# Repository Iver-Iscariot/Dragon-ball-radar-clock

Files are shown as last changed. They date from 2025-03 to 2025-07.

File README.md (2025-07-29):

# Dragon ball radar watch
A clock based on the dragon-radar from Dragon Ball.<br>
Very basic, pocket watch-style clock, with two rings of 12 LED's (hour/minute).<br>
At the press of the top button, the hour and minute (rounded to closest five) will pulse a couple of times, like in the anime.
&nbsp;

As this will be a novelty item that I only use once in a while, I will forgo a proper RTC, and just rely on the MCU itself for timekeeping. 
To work with the one-button interface of the original, I will set it such that a long-press will set the time to 12 o'clock, so you can simply set it when the actual time is 12 am or pm.<br>

&nbsp;



Progress so far. I need to turn a housing on the lathe

## VERY organized scematic:



## TODO for next PCB itteration:
 - Mosfet poweroff for 4052 multiplexer (power-saving)
 - Perhaps figure out more efficient way of driving the matrix than 4052 (IS31FL3746A LED driver ?)
 - Consider using dedicated RTC, to allow MCU sleep (power saving)
 - Attempt to move LED rings closer to center and make it smaller (LED driver chip would reduce total component footprint)
 - Try out a different LIPO charging circuit (there HAS to be a better way)

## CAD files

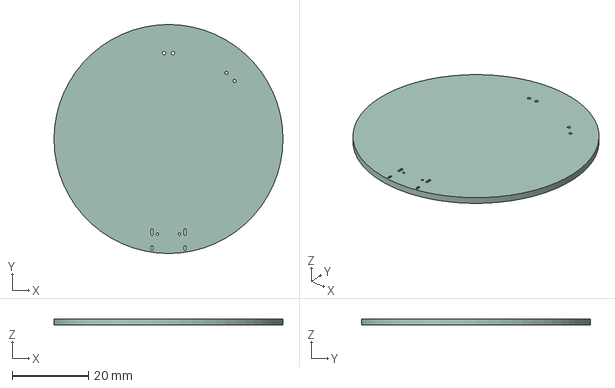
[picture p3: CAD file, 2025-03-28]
DB-radar/DB-radar.step
60.0 x 60.0 x 1.60 mm

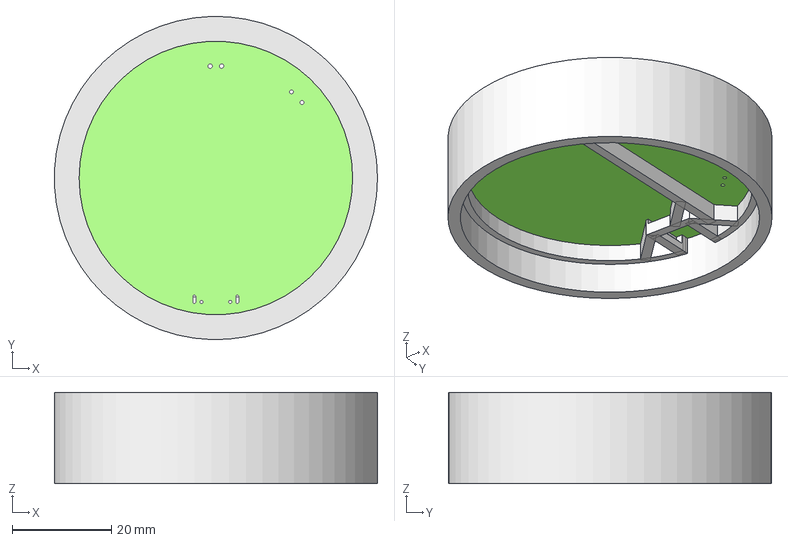
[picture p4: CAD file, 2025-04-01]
supportframes.FCStd
65.0 x 65.0 x 18.3 mm
DB-radar PCB
Front Spacer
Back support
Plexiglass

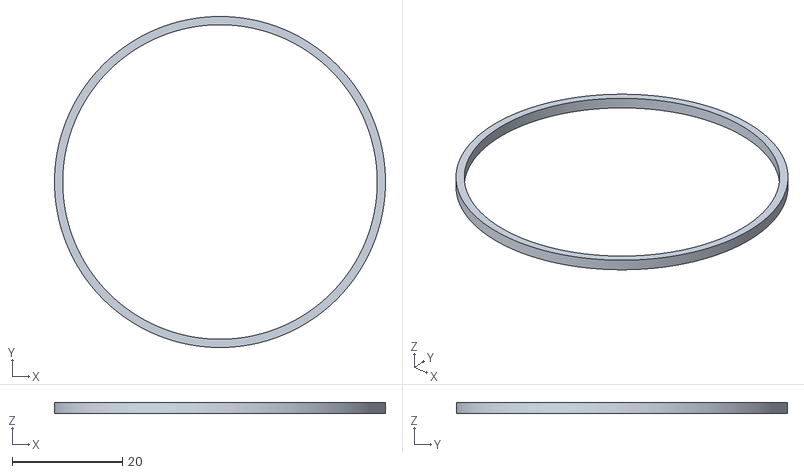
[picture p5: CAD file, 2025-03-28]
front spacer.stl
60.0 x 60.0 x 2.00

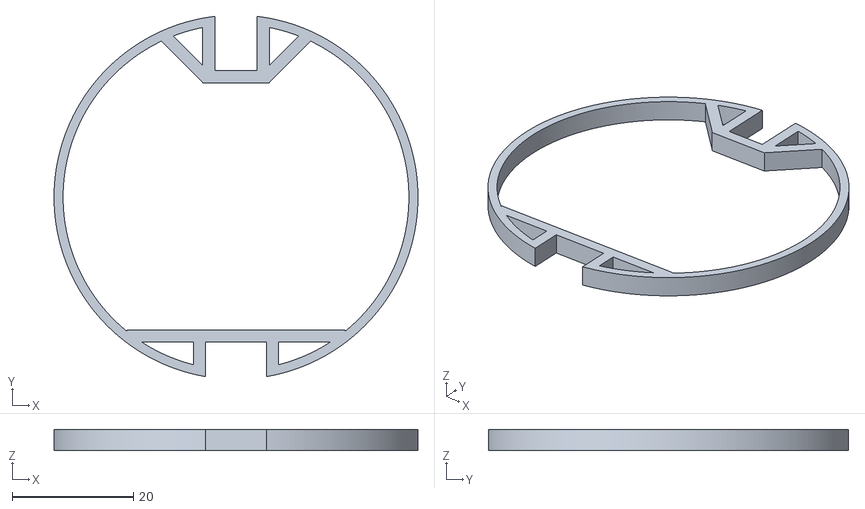
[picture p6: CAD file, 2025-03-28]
usb side.stl
60.0 x 59.4 x 3.50

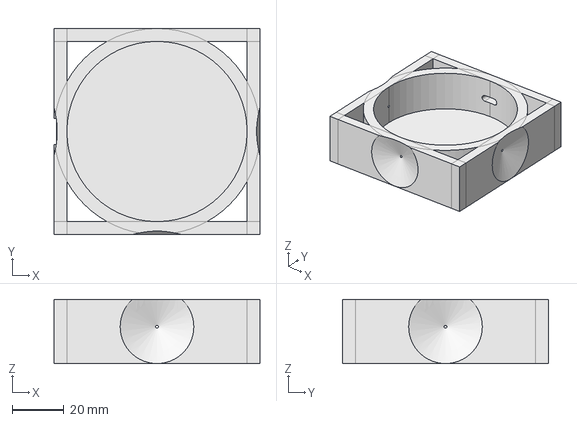
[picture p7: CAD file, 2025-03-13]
Drill guide 3D print.FCStd
80.0 x 80.0 x 25.0 mm

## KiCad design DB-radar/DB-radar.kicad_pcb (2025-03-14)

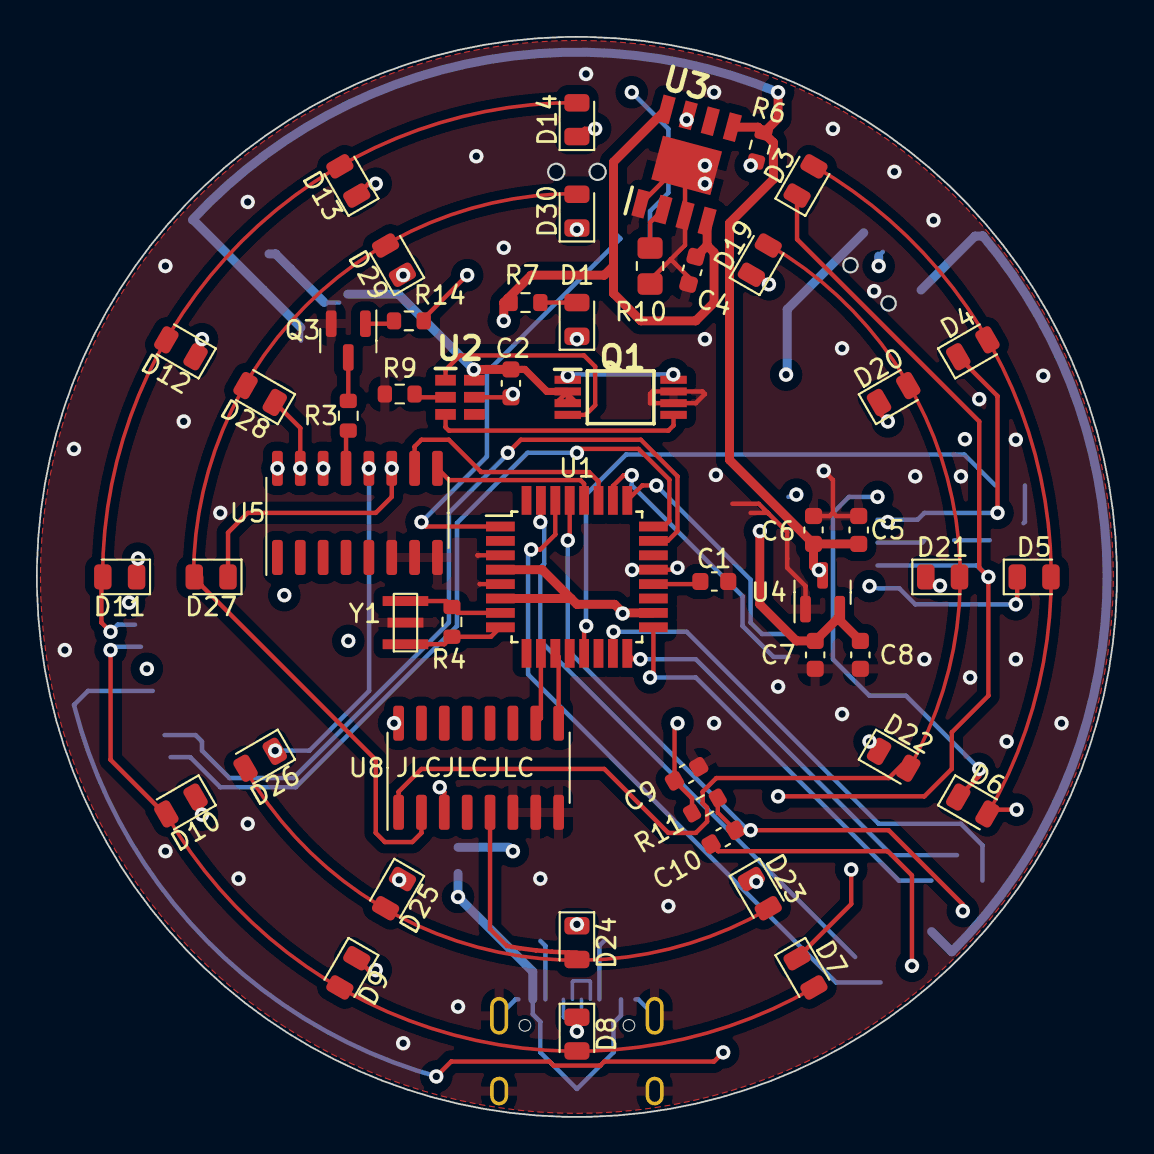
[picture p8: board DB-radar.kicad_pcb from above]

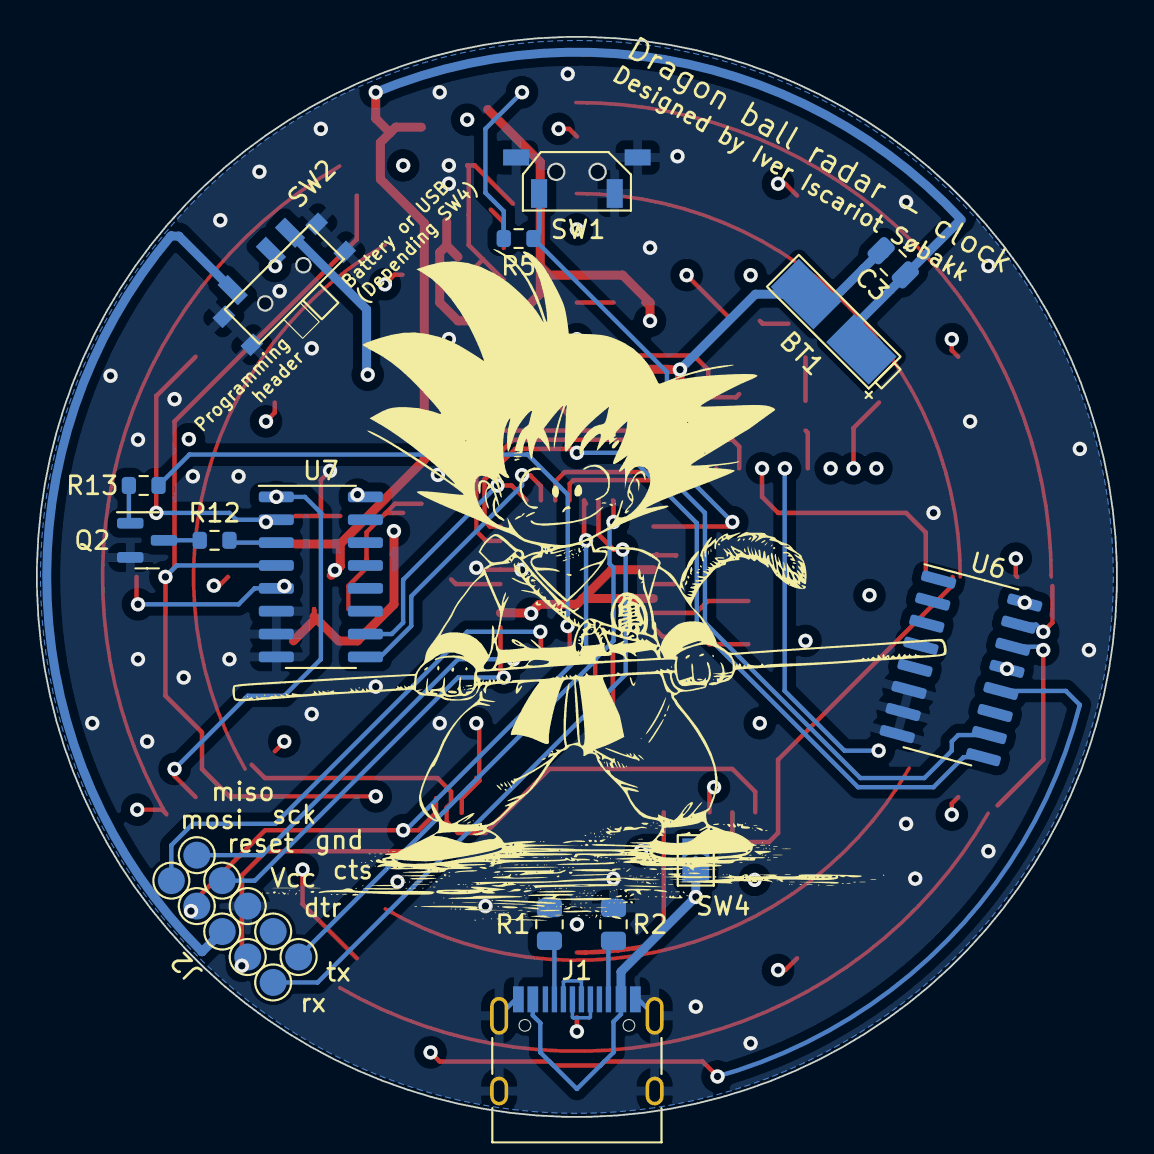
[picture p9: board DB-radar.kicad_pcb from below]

Board: 4 copper layers, 60.0 x 60.0 mm, 66 parts (15 on the bottom side), 59 nets.

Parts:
BT1: Battery_Cell; battery pad
C1, C5, C7, C9, C10: 0.1uF; C_0603_1608Metric
C2, C4: 100nF; C_0603_1608Metric
C3: 10uF; C_0805_2012Metric
C6, C8: 1uF; C_0603_1608Metric
D1, D3, D4, D5, D6, D7, D8, D9, D10, D11, D12, D13, D14, D19, D20, D21, D22, D23, D24, D25, D26, D27, D28, D29, D30: LED; LED_0805_2012Metric
J1: USB_C_Receptacle; USB_C_Receptacle_HRO_TYPE-C-31-M-12
J2: Conn_01x10_Female; solder-pad-10-2mm
Q1: FS8205A; SOP65P640X120-8N
Q2, Q3: PN2222A; MMBT2222A
R1, R2: 5.1K; R_0805_2012Metric
R3, R6, R12: 100; R_0603_1608Metric
R4: 1M; R_0603_1608Metric
R5: 2K; R_0603_1608Metric
R7, R9: 1k; R_0603_1608Metric
R10: 1k; R_0805_2012Metric_Pad1.20x1.40mm_HandSolder
R11: 10K; R_0603_1608Metric
R13, R14: 1K; R_0603_1608Metric
SW1: SW_Push; side button
SW2: SW_SPDT; MSK-12C02
SW4: SW_MEC_5G; SolderJumper-2_P1.3mm_Open_TrianglePad1.0x1.5mm
U1: ATmega328PB-A; TQFP-32_7x7mm_P0.8mm
U2: DW01A-G; SOT95P190X145-6N
U3: TP4056; SOIC127P600X175-9N
U4: XC6206PxxxMR; SOT-23
U5, U6, U7, U8: 4052; SOIC-16_3.9x9.9mm_P1.27mm
Y1: Crystal_GND3_Small; 3213 crystal

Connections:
5V: C4.1, J1.A4 (VBUS), J1.A9 (VBUS), J1.B4 (VBUS), J1.B9 (VBUS), R7.1, SW4.1 (A), U3.4 (VCC4), U3.8 (CE)
-BATT: BT1.2 (-), C2.2, C3.2, Q1.2 (S1_1), Q1.3 (S1_2), U2.6 (GND)
A: U1.23 (PC0), U6.10 (A)
B: U1.24 (PC1), U6.9 (B)
BAT+: BT1.1 (+), C3.1, C5.2, C6.2, R6.2, SW4.2 (B), U3.5 (BAT), U4.3 (VI)
BUT_3: R5.2, SW1.2, U1.1 (PD3)
C: U1.25 (PC2), U7.10 (A)
D: U1.26 (PC3), U7.9 (B)
D+: J1.A6 (D+), J1.B6 (D+)
D-: J1.A7 (D-), J1.B7 (D-)
DTR: C10.1, J2.3
E: U1.27 (PC4), U5.10 (A)
F: U1.28 (PC5), U5.9 (B)
G: U1.10 (PD6), U8.10 (A)
GND: C1.1, C4.2, C5.1, C6.1, C7.1, C8.1, C9.2, J1.A1 (GND), J1.A12 (GND), J1.B1 (GND), J1.B12 (GND), J1.S1 (SHIELD), J2.6, Q1.6 (S2_1), Q1.7 (S2_2), Q2.1 (E), Q3.1 (E), R1.1, R2.1, R9.1, R10.1, SW1.1, SW2.S (Shield), U1.3 (PE0), U1.5 (GND), U1.21 (GND), U3.1 (TEMP1), U3.3 (GND_3), U3.9 (EP), U4.1 (GND), U5.6 (Inh), U5.7 (VEE), U5.8 (VSS), U6.6 (Inh), U6.7 (VEE), U6.8 (VSS), U7.6 (Inh), U7.7 (VEE), U7.8 (VSS), U8.6 (Inh), U8.7 (VEE), U8.8 (VSS), Y1.3
H: U1.11 (PD7), U8.9 (B)
LED_PWM: R13.2, R14.2, U1.13 (PB1)
MISO: J2.10, U1.16 (PB4)
MOSI: J2.9, U1.15 (PB3)
unnamed: D1.2 (A), R7.2
unnamed: D1.1 (K), U3.7 (~CHRG)
unnamed: D3.2 (A), D4.2 (A), D5.2 (A), D6.2 (A), U6.12 (X0)
unnamed: D7.2 (A), D8.2 (A), D9.2 (A), D10.2 (A), U6.14 (X1)
unnamed: D6.1 (K), D10.1 (K), D14.1 (K), U7.1 (Y0)
unnamed: D11.2 (A), D12.2 (A), D13.2 (A), D14.2 (A), U6.15 (X2)
unnamed: D3.1 (K), D7.1 (K), D11.1 (K), U7.4 (Y3)
unnamed: D4.1 (K), D8.1 (K), D12.1 (K), U7.2 (Y2)
unnamed: D5.1 (K), D9.1 (K), D13.1 (K), U7.5 (Y1)
unnamed: D19.2 (A), D20.2 (A), D21.2 (A), D22.2 (A), U8.1 (Y0)
unnamed: D19.1 (K), D23.1 (K), D27.1 (K), U5.11 (X3)
unnamed: D20.1 (K), D24.1 (K), D28.1 (K), U5.15 (X2)
unnamed: D21.1 (K), D25.1 (K), D29.1 (K), U5.14 (X1)
unnamed: D22.1 (K), D26.1 (K), D30.1 (K), U5.12 (X0)
unnamed: D23.2 (A), D24.2 (A), D25.2 (A), D26.2 (A), U8.5 (Y1)
unnamed: D27.2 (A), D28.2 (A), D29.2 (A), D30.2 (A), U8.2 (Y2)
unnamed: J1.A5 (CC1), R1.2
unnamed: J1.B5 (CC2), R2.2
unnamed: Q1.1 (D12_1), Q1.8 (D12_2)
unnamed: Q1.4 (G1), U2.1 (OD)
unnamed: Q1.5 (G2), U2.3 (OC)
unnamed: Q2.2 (B), R13.1
unnamed: Q2.3 (C), R12.2
unnamed: Q3.2 (B), R14.1
unnamed: Q3.3 (C), R3.2
unnamed: C1.2, U1.20 (AREF)
unnamed: R4.1, U1.7 (XTAL1/PB6), Y1.2
unnamed: R4.2, U1.8 (XTAL2/PB7), Y1.1
unnamed: R9.2, U2.2 (CS)
unnamed: C2.1, R6.1, U2.5 (VCC)
unnamed: R10.2, U3.2 (PROG2)
unnamed: R3.1, U5.13 (X)
unnamed: R12.1, U7.3 (Y)
RESET: C10.2, J2.7, R11.2, U1.29 (~RESET/PC6)
RX: J2.1, U1.30 (PD0)
SCK: J2.8, U1.17 (PB5)
TX: J2.2, U1.31 (PD1)
VCC: C9.1, R5.1, R11.1, SW2.2 (B), U1.4 (VCC), U1.6 (PE1), U1.18 (AVCC), U5.16 (VDD), U6.13 (X), U6.16 (VDD), U7.16 (VDD), U8.3 (Y), U8.16 (VDD)
VCC_bat: C7.2, C8.2, SW2.1 (A), U4.2 (VO)
VCC_prog: J2.5, SW2.3 (C)

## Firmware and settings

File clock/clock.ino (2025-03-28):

/*
  Dragon-radar clock
  Script written by Iver Iscariot Søbakk, for his custom PCB with an Atmega328 (open source at the github you found this file)
*/
#include <TimeLib.h>
#include <LowPower.h>


#define BUTTON_PIN 3  // Pin for the button

int PWM = 9;             // the PWM pin the transistors are attached to

int A = 14; int B = 15;  // Minute cathode 
int C = 16; int D = 17;  // Minute anode 

int E = 18; int F = 19;  // Hour cathode 
int G = 6 ; int H = 7 ;  // Hour anode

// --- Time-showing-pulses
int maxBright = 127;  // Maximum Brightness
float period = 0.5;       // Period of fade (in seconds)
int n = 3;            // Number of pulses

// bools and timers for long/short buttonpress functionality
bool buttonActive = false;
bool longPressActive = false;
unsigned long buttonTimer = 0;
unsigned long longPressTime = 3000;


// Define the HOUR/MIN pin states to select the correct LED from the two "matrix"es (see schematic)
const byte pinStatesH[12][4] = {
    {0, 0, 1, 1}, // 1 -> 0011
    {0, 0, 1, 0}, // 2 -> 0010
    {0, 0, 0, 1}, // 3 -> 0001
    {0, 0, 0, 0}, // 4 -> 0000
    {0, 1, 1, 1}, // 5 -> 0111
    {0, 1, 1, 0}, // 6 -> 0110
    {0, 1, 0, 1}, // 7 -> 0101
    {0, 1, 0, 0}, // 8 -> 0100
    {1, 0, 1, 1}, // 9 -> 1011
    {1, 0, 1, 0}, // 10 -> 1010
    {1, 0, 0, 1}, // 11 -> 1001
    {1, 0, 0, 0}  // 12 -> 1000
};
const byte pinStates[12][4] = {
    {0, 0, 1, 1}, // 1  -> 0011
    {0, 0, 0, 1}, // 2  -> 0001
    {0, 0, 1, 0}, // 3  -> 0010
    {0, 0, 0, 0}, // 4  -> 0000
    {1, 0, 1, 1}, // 5 -> 1011
    {1, 0, 0, 1}, // 6 -> 1001
    {1, 0, 1, 0}, // 7 -> 1010
    {1, 0, 0, 0},  // 8 -> 1000
    {0, 1, 1, 1}, // 9  -> 0111
    {0, 1, 0, 1}, // 10 -> 0101
    {0, 1, 1, 0}, // 11 -> 0110
    {0, 1, 0, 0} // 12 -> 0100
};


// --------------------------- Functions to be called -----------------------------------
void setMinute(int inputNumber) {    
    inputNumber = inputNumber/5 + 1; // divides to the nearest 5 minutes, rounding up, so yu have more time than you think 4 -> 0+1, lighting the "5 min" led
    if (inputNumber < 1 || inputNumber > 12) return; // Ensure valid range
    
    digitalWrite(A, pinStates[inputNumber - 1][0]);
    digitalWrite(B, pinStates[inputNumber - 1][1]);
    digitalWrite(C, pinStates[inputNumber - 1][2]);
    digitalWrite(D, pinStates[inputNumber - 1][3]);
}

void setHour(int inputNumber) {    
    if (inputNumber < 1 || inputNumber > 12) return; // Ensure valid range
    
    digitalWrite(E, pinStatesH[inputNumber - 1][3]);
    digitalWrite(F, pinStatesH[inputNumber - 1][2]);
    digitalWrite(G, pinStatesH[inputNumber - 1][1]);
    digitalWrite(H, pinStatesH[inputNumber - 1][0]);
}

void resetClock(){
  // Set time to 12:00:00
  setTime(12, 0, 0, 1, 1, 2025); // setTime(hr, min, sec, day, month, year)
}

void showTime(){
  Serial.println("Showing time");
  setHour(hour());      // Set the pins for the LED matrix
  setMinute(minute());
  unsigned long t0 = millis();
  // PWM a sine on the pwm pin for the set amunt of periods
  while (millis() - t0 < n*period*1000){
    analogWrite(PWM, maxBright*0.5*(         cos(    2*PI*( millis()-t0 )/( 1000*period )    + PI)   + 1       )  ); 
    delay(5);  // if you want realy fast pulses for some reason, you might want to reduce this
  }
  analogWrite(PWM, 0);

}


// ------------------------------------ Setup ---------------------------------------------
void setup() {
  pinMode(PWM, OUTPUT);
  pinMode(BUTTON_PIN, INPUT);
  
  pinMode(A, OUTPUT); pinMode(B, OUTPUT); pinMode(C, OUTPUT); pinMode(D, OUTPUT);
  pinMode(E, OUTPUT); pinMode(F, OUTPUT); pinMode(G, OUTPUT); pinMode(H, OUTPUT);

  // Dont know if this is strictly necesarry
  digitalWrite(A, LOW);  digitalWrite(B, LOW);  digitalWrite(C, LOW);  digitalWrite(D, LOW);  
  digitalWrite(E, LOW);  digitalWrite(F, LOW);  digitalWrite(G, LOW);  digitalWrite(H, LOW);  

  Serial.begin(9600);


  hourFormat12(); 
  delay(250);
  resetClock();
  delay(250);
  setHour(hour());      // Set the pins for the LED matrix
  setMinute(minute());
  delay(250);
  showTime();
  delay(250);
}

// ---------------------------------------- Loop ----------------------------------------------
void loop() {

	if (digitalRead(BUTTON_PIN) == LOW) {  // the button is active low / pulled high

		if (buttonActive == false) {

			buttonActive = true;
			buttonTimer = millis();
		}

		if ((millis() - buttonTimer > longPressTime) && (longPressActive == false)  ) {
      if (digitalRead(BUTTON_PIN) == HIGH) {
        longPressActive = true;
        resetClock();
        showTime();
      }
		}

	} else {

		if (buttonActive == true) {

			if (longPressActive == true) {

				longPressActive = false;

			} else {

				showTime();

			}

			buttonActive = false;

		}

	}
}

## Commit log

2025-01-03 Made file and started schematic
    Mostly imported from earlier projects.
    Still need to add LED's and multiplexer matrix.
    Note to self: Only need one resistor for minutes and one per hour, as only one will be on at the time
    note: remember to drive LEDs with a PWM pin
    [DB-radar.kicad_pcb, DB-radar.kicad_sch]
2025-01-04 Added LED and multiplexers and started PCB design
    [DB-radar.kicad_pcb, DB-radar.kicad_sch]
2025-01-06 De fleste komponenter plassert
    Mangler bare et par blokker og routing
    [DB-radar.kicad_pcb, DB-radar.kicad_sch]
2025-01-07 Begynnt å route
    Mega-rotete
    [DB-radar.kicad_pcb, DB-radar.kicad_sch]
2025-01-08 Økte til 4 layers og routet ferdig
    Har også kjørt DRC, og det eneste som gjenstår er en GND Zone som den påstår ikke er connected
    [DB-radar.kicad_pcb]
2025-01-09 Fulførte routing og passed DRC
    [DB-radar-B_Cu.gbr, DB-radar-B_Mask.gbr, DB-radar-B_Paste.gbr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]
2025-03-13 Se på sketch
    [Drill guide 3D print.FCStd]
2025-03-14 fikset silk bak
    Byttet strøm-selector og SPI kommentarer
    [DB-radar.kicad_pcb]
2025-03-15 Working demo
    Last one had wrong lookuptable for outer ring, and minutes and hour switched around
    [clock.ino]
2025-03-15 Begun on actual clock code with button wake-up
2025-03-28 Fake sleep. Hour not working
    [DB-radar.step, front spacer.stl, supportframes.FCStd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]
2025-04-01 3D model for hus
    [supportframes.FCStd]
